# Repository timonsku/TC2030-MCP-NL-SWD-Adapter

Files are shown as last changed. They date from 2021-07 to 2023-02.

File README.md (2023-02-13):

# TC2030-MCP-NL-SWD-Adapter

Works for both NL and hook version of course. NL is just what I personally use.
Breaks out the RJ12 connector from the TC2030-MCP to common SWD connectors and standard pin headers.
Tested with actual target PCB to be following the pinout correctly.

BOM
----

- Molex 95501-6669 (RJ12)
- Samtec FTR-105-02-G-D (2x5 pin 1.27mm SMT un-shrouded) (or use the typical shrouded connector) Cheaper here: https://s.click.aliexpress.com/e/_A3X57A
- Molex 90130-1110 (2x5 2.54mm PTH Shrouded)
- Molex 90130-1120 (2x10 2.54mm PTH Shrouded)

For the cable itself, the following Mouser PNs are the MCP variant:

NL version:
- 579-TC2030-MCP-NL 

With hooks:
- 733-53025-851
- 579-TC2030-MCP

For DigiKey:
- TC2030-MCP-NLTC-ND
- TC2030-MCPTC-ND

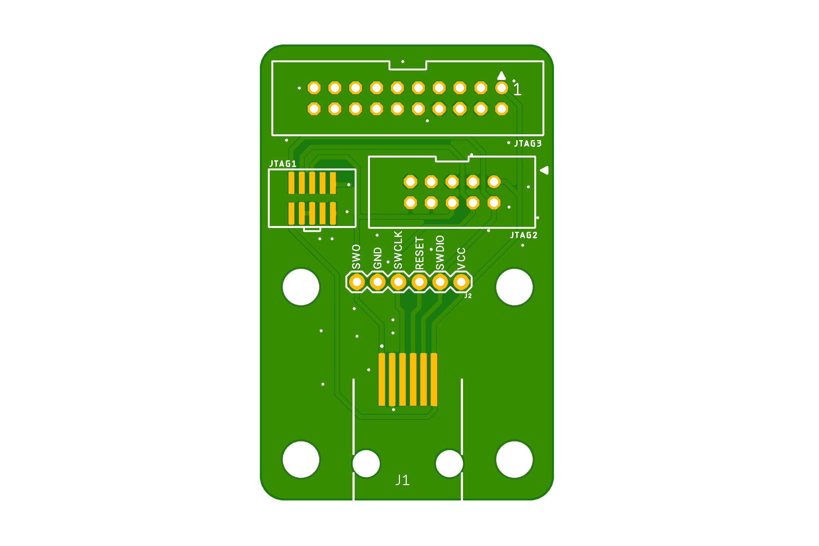
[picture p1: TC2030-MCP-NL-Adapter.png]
Preview


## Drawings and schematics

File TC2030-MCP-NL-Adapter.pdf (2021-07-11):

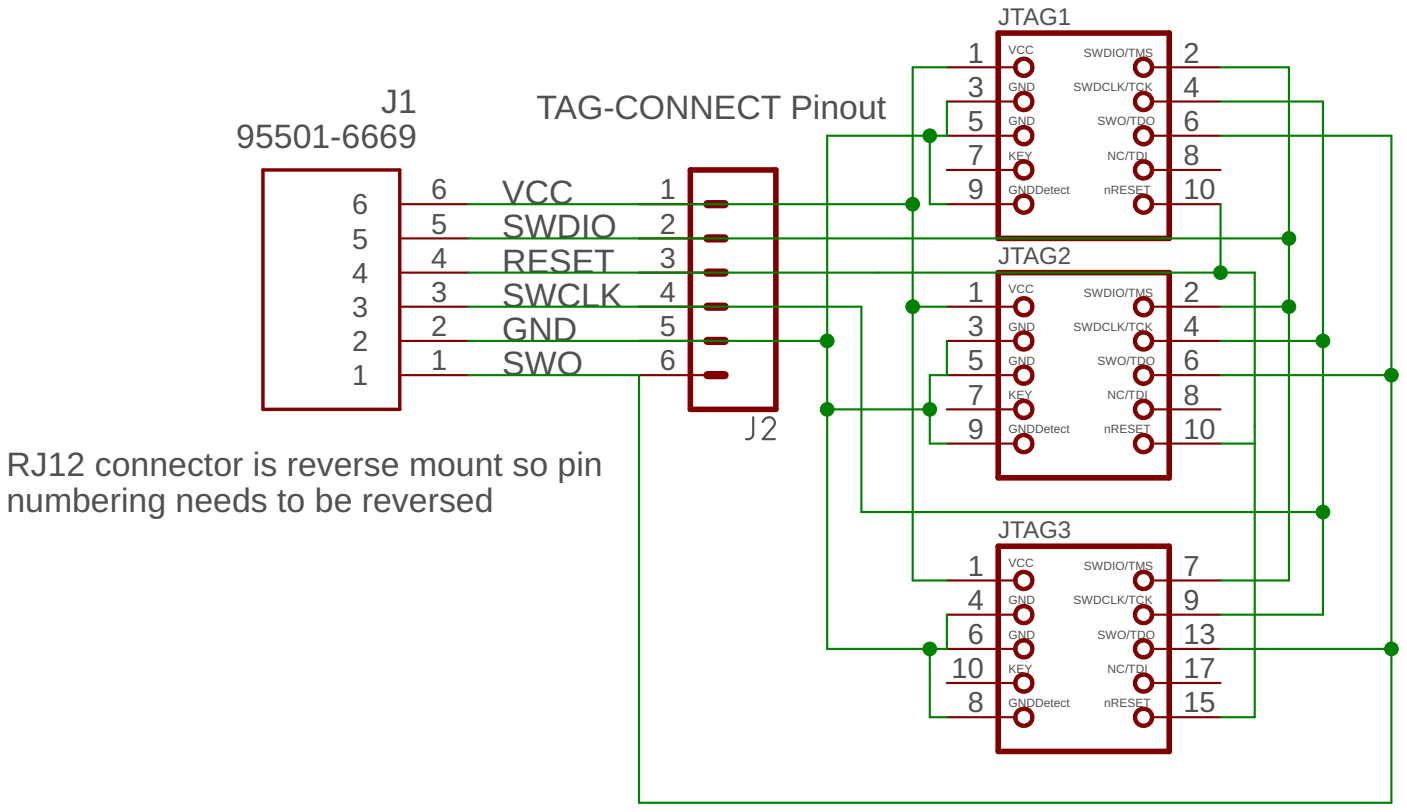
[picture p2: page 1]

nRESET NC/TDI SWO/TDO

5 SWDIO 2
3 4 RESET | JTAG2
3 SWCLK 4 | | VCC SWDIO/TMS GND GND SWDCLK/TCK nRESET NC/TDI SWO/TDO
2 GND 5

RJ12 connector is reverse mount so pin
numbering needs to be reversed

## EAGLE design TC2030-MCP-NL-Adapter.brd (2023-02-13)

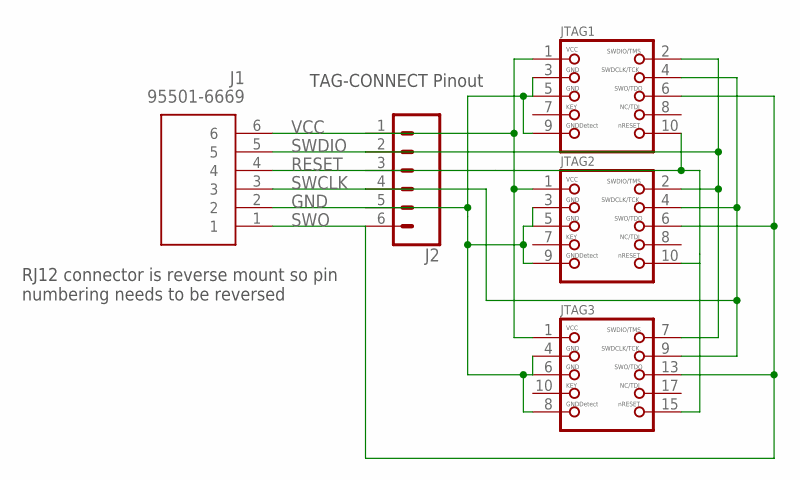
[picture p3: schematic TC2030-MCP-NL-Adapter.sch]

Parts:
J1: 95501-6669
J2: CONN_06SILK_FEMALE_PTH; 1X06
JTAG1: JTAG-CORTEXM3; 2X05_1.27MM_SMT
JTAG2: JTAG-CORTEXM3MOLEX; CORTEXM3_SWD10_MOLEX
JTAG3: JTAG-CORTEXM3MOLEX20; JTAG-ARM

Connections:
GND: J1.2, J2.5, JTAG1.3, JTAG1.5, JTAG1.9, JTAG2.3, JTAG2.5, JTAG2.9, JTAG3.4 (3), JTAG3.6 (5), JTAG3.8 (9)
RESET: J1.4, J2.3, JTAG1.10, JTAG2.10, JTAG3.15 (10)
SWCLK: J1.3, J2.4, JTAG1.4, JTAG2.4, JTAG3.9 (4)
SWDIO: J1.5, J2.2, JTAG1.2, JTAG2.2, JTAG3.7 (2)
SWO: J1.1, J2.6, JTAG1.6, JTAG2.6, JTAG3.13 (6)
VCC: J1.6, J2.1, JTAG1.1, JTAG2.1, JTAG3.1

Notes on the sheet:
TAG-CONNECT Pinout
RJ12 connector is reverse mount so pin numbering needs to be reversed

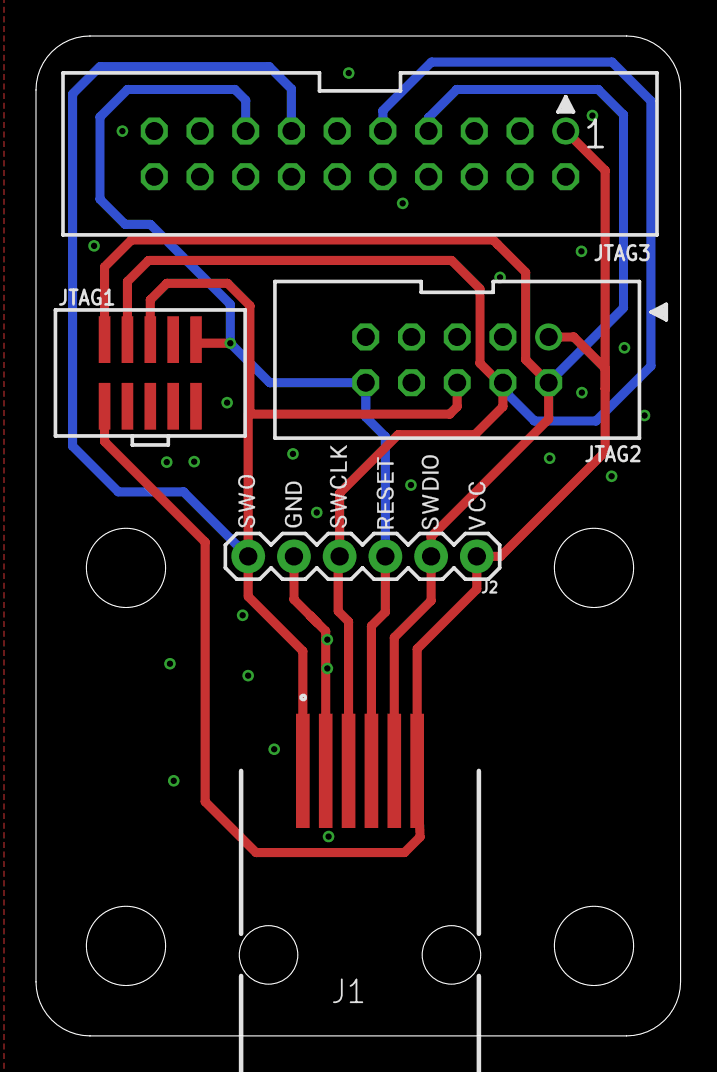
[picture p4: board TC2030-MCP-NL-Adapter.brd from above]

Board: 2 copper layers, 35.8 x 55.5 mm, 11 parts (0 on the bottom side), 6 nets.

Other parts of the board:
U$1: SWO0
U$2: GND0
U$3: SWCLK0
U$4: RESET0
U$5: SWDIO0
U$6: VCC0

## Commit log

2021-07-11 add board files
    [TC2030-MCP-NL-Adapter.brd, TC2030-MCP-NL-Adapter.sch]
2021-07-11 add BOM
2021-07-11 rename gerbers archive
2021-12-26 add pn for cable
2023-02-13 fix SWDIO short to GND
    [TC2030-MCP-NL-Adapter.brd]

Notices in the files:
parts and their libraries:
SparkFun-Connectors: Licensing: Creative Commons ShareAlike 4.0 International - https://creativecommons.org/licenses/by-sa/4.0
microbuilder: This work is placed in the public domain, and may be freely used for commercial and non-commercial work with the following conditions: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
